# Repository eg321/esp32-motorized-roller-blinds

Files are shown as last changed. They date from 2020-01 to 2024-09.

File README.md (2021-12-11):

*Russian version available [here](README_ru.md)*.

Hi there!

The project is dedictated to control of motorized blinds’ operation and its integration into home automation systems (f.ex. [Home Assistant](https://www.home-assistant.io/) and [OpenHab](https://www.openhab.org/)).

The project developing consists of 2 major areas:

- Software (firmware for boards based at ESP8266 / ESP32 modules)
- Hardware/Mechanical (3d printing models to upgrade your blinds into motorized).

A bit details below...

# ESP8266 / ESP32 firmware
I'm trying to keep compatibility with both platforms.
Main differences between them:
- There is fewer pins available at ESP8266. You can connect 2 steppers to single controller only (using 8 pins).  
- ESP32 can connect up to 4 steppers (or even more?) to single controller (using 16 pins).

If you would to connect 1 or 2 steppers only, use cheaper ESP8266 based controller (like Wemos D1 mini, NodeMCU, etc).

## Features
- Support for cheap 28BYJ-48 steppers (better to use 12 volt versions)
- Control of an unlimited number of steppers (limitation in 4 motors is the default for a more convenient UI). In fact, it's limited by hardware only (by the number of pins).
- Ability to set the rotation speed (12 volt motors can provide a higher speed)
- Ability to set all main settings through  Captive WiFi Portal (steppers used, pins, rotation speed, MQTT settings, etc.)
- Web interface for setting endpoints and controlling blinds (adapted for mobile devices also)
- Possibility of connecting an external mechanical switch (with the ability to stop the curtains in the desired position).
- MQTT support (both for controlling curtains and for setting end positions - can be complete replacement for Web UI)
- Easy integration with popular home automation systems like [Home Assistant](https://www.home-assistant.io/) or [OpenHab](https://www.openhab.org/) (via MQTT)
- Over the air (OTA) updates. No need to disconnect or disassemble the controller to update the firmware. The web interface notifies about the availability of new updates.
- Saving the position of each blind in the ROM (you do not need to re-calibrate or set the position after turning off the power)
- Control of all connected motors in parallel (asynchronous operation with steppers)
- Watchdog (automatic restart of the controller in case of freezing)
- Automatic MQTT re-connection in case of network problems
- Low power consumption when idle (stepper windings are switched-off when idle)
- DHCP over WiFi support

## Web-interface
Control blinds:



Set end-points:



## Captive Portal
You'll be redirected to Captive portal after connecting to "esp-xxxx" WiFi network:



Fill pins for needed Steppers divided by comma and check pins for your mechanical buttons Up/Down (or disable it).

## MQTT
*Just do not setup MQTT details at Captive Portal, if you don't want to use MQTT.*

MQTT details:
- Controller listening for commands at topic `ESP_Blinds/<chip_id>/in` (JSON)
- Controller send updates with state and positions to `ESP_Blinds/<chip_id>/out` (JSON)
- Separate topics for steppers (`/outN`) are disabled for MQTT messaging optimization, but you can enable it if needed for your automation flow.

## HomeAssistant integration
There is MQTT auto-discovery implemented for HomeAssistant with default MQTT prefix (requires HA v2021.11 at least). It assists you to create objects with correct configuration.

In case it does not work for you, you can add blinds manually. See examples below. 


Config example for 2 roller blinds (replace "_chip_Id_" with Chip id of your controller, watch it at registration topic - `/ESP_Blinds/register`):
```yaml
cover:
  - platform: mqtt
    name: "Blind 1"
    device_class: "blind"
    command_topic: "ESP_Blinds/_chip_Id_/in"
    set_position_topic: "ESP_Blinds/_chip_Id_/in"
    set_position_template: '{"num": 1, "action": "auto", "value": {{ 100 - position }} }'
    position_topic: "ESP_Blinds/_chip_Id_/out"
    position_template: '{{ value_json.position1 }}'
    payload_open: '{"num": 1, "action": "auto", "value": 0}'
    payload_close: '{"num": 1, "action": "auto", "value": 100}'
    payload_stop: '{"num": 1, "action": "stop", "value": 0}'
    position_open: 0
    position_closed: 100
    optimistic: false

  - platform: mqtt
    name: "Blind 2"
    device_class: "blind"
    command_topic: "ESP_Blinds/_chip_Id_/in"
    set_position_topic: "ESP_Blinds/_chip_Id_/in"
    set_position_template: '{"num": 2, "action": "auto", "value": {{ 100 - position }} }'
    position_topic: "ESP_Blinds/_chip_Id_/out"
    position_template: '{{ value_json.position2 }}'
    payload_open: '{"num": 2, "action": "auto", "value": 0}'
    payload_close: '{"num": 2, "action": "auto", "value": 100}'
    payload_stop: '{"num": 2, "action": "stop", "value": 0}'
    position_open: 0
    position_closed: 100
    optimistic: false
```
Use same approach for other your blinds.

# Mechanical part
The most popular option uses cheap 28BYJ-48 steppers, but in fact you can use any 4-pin stepper motors (dual winding steppers).
28BYJ-48 is most often used with the ULN2003 driver (better to use 12 volt version, it gives more torque).

I have developed 2 models for converting Leroy Merlin' roller blinds into motorized ones:
1. for the old models. It looks like they are almost not sold anymore.
2. for a new (will publish soon). The fixing holes match the original parts, so the curtains can be easily converted to motorized and vice versa.

3 printing models are available at `3d_parts` directory or at [Thingiverse](https://www.thingiverse.com/thing:4093205/) directly with some instructions.

# Future plans
* Add support for other steppers and drivers (please propose at "issues")
* Add more configuration options at WebUI to allow re-configuration without "wipe settings"
* Prepare universal PCB
* Any ideas? Fill in the Issues.

# Project history
This project appeared as fork of @nidayand [repository](https://github.com/nidayand/motor-on-roller-blind-ws) originally.

Unfortunately, the project supported ESP8266 and 1 stepper only, plus it had not been updated for a long time. I added support for Platformio (for easier development), multiple steppers, and ESP32 later (so more than 2 steppers can be connected to single controller). It was published as v1.4.x.

Soon I wanted a more convenient motor control, a simple controller configuration without firmware re-build, but the original code was of little messy to maintain, although it worked.
As a result, a large refactoring of the firmware took place - new classes and areas of responsibility were allocated.

In fact, it became clear that almost nothing remained of the old project (only the Web UI almost unchanged). This project was detached and now developing on its own tree.

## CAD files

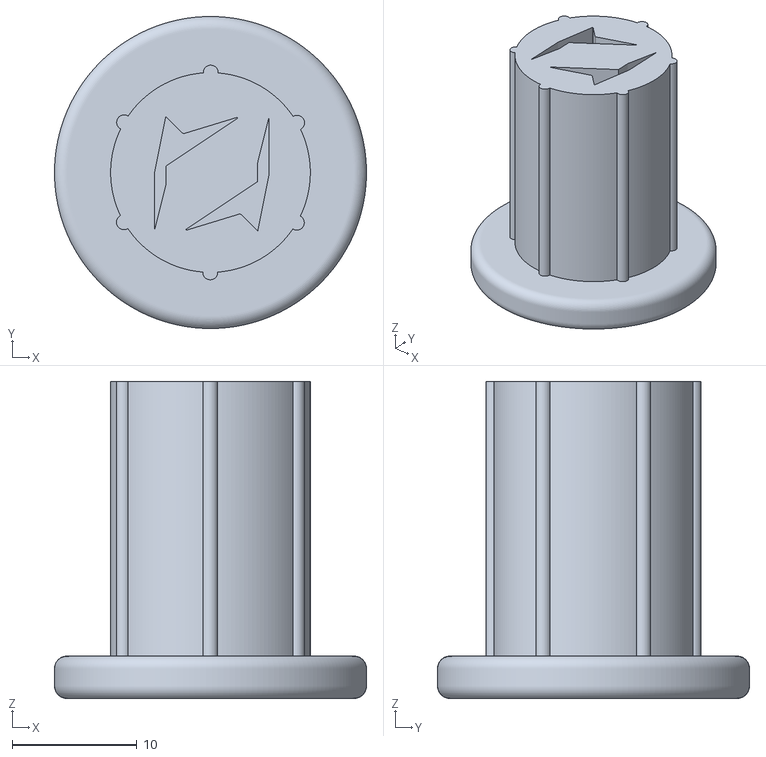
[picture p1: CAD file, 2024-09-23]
3d_parts/Ozon home blind shaft (direct drive).stl
25.0 x 25.0 x 25.4

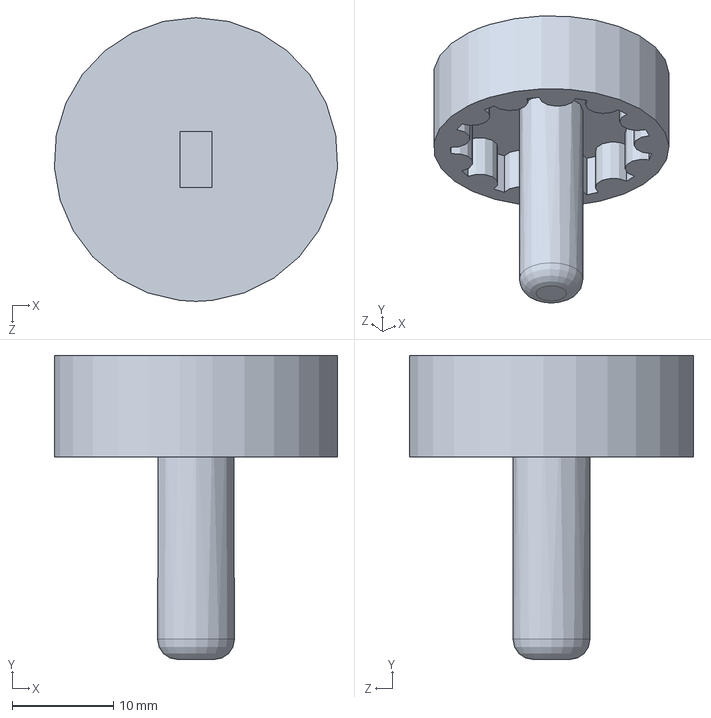
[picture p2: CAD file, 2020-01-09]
3d_parts/Leroy Merlin blind holder (direct drive).SLDPRT
28.0 x 30.0 x 28.0 mm

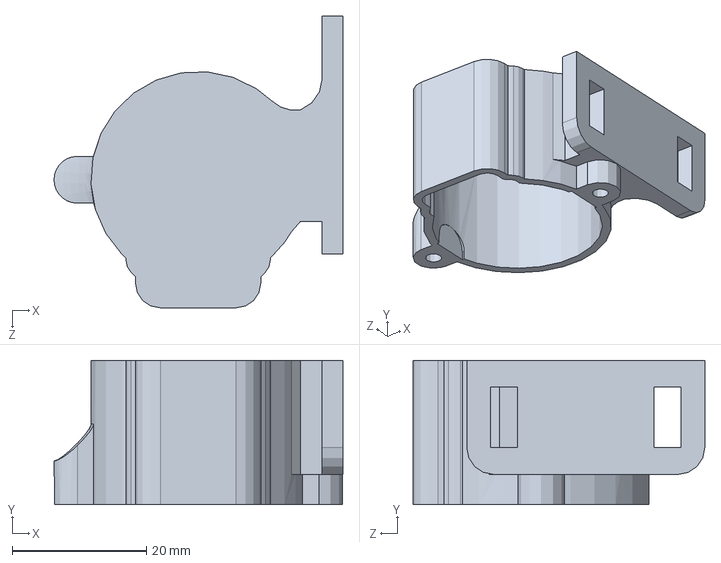
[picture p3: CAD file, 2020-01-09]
3d_parts/Motor holder (direct drive).SLDPRT
43.1 x 21.5 x 43.5 mm

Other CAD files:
3d_parts/Leroy Merlin blind holder (direct drive).STL
3d_parts/Motor holder (direct drive).STL

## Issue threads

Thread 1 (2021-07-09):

static ip and watchdog

iw88881111, 2021-07-09:
Thanks for great project and freeware it :) It's realy working in my SmartHome system (mechanical part another) for three month.
Now, I have 2 suggestions for update (discussed earlier) :
1. Abbility to assign ESP static IP address.
2. Watchdog attached to router/ip address/server etc.

Many thanks
WBR, Igor.

eg321, 2021-08-14:
Hi!

1. Unfortunately "ESP-WiFiSettings" library does not support static IP configuration now. The best option is to request such feature there (highlighting @Juerd). Once they implement it, I'll try to use it here also.
2. There is configured watchdog already. It checks that ESP is working ok and restarting it on any issue. Another part is MQTT - there is automatic reconnection also. One thing that definitely needed to be improved is WiFi connection.
It looks like controller does not reconnect automatically to WiFi. I'll check how we can process this, but as quick workaround I've added possibility to restart board from mechanical switch with 5 clicks. It looks safe, but maybe useful in such situations.
It will be released in v2.0.1.

I'll keep open this issue for now.

iw88881111, 2021-08-22:
Hi!
Maybe set IP/MASK in the main.cpp code?
It's will solved bug :)

eg321, 2021-11-07:
@iw88881111 Igor, I've implemented additional checks for WiFi connectivity. By now it uses such workflow:
1. Once WiFi is disconnected, it waits for 15 min for connection restoration.
2. Once 15 minutes is expired and still no WiFi connection is detected, device is going to restart. Timer is started again for another 15 minutes.

Please note:
1. After restart it can switch to Captive Portal mode, if no WiFi connection still detected. I don't like this, because Captive portal is public and anyone can connect to it during this period, but I cannot find better solution now.
2.  ESP8266 can restore connection immediately without reboot, but ESP32 requires reboot to properly maintain connection (so it always will wait for 15 minutes to expire and try to connect after restart).
3. Device continues handle buttons despite WiFi connection issues (even in Captive portal mode).

I've checked that at my ESP8266 and ESP32 and it works ok for me. You can check these changes at master, if you want.
Later I'll include them into the new release, if no new issues appears.

iw88881111, 2021-11-16:
Hi!
Very well. I wil try new firmware.

eg321, 2022-09-28:
It's not a good practice to make static IP on devices and manage them individually in the network. This should be done at DHCP server side. Almost all routers support this.

I'm closing this issue, because I believe that IP management shouldn't be a part of this device.

Closed 2022-09-28.

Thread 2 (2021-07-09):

turn motor speed (variable)

iw88881111, 2021-07-09:
In testing, when blinds have more length 28byj can not up it.
I change variable "motor speed" to low level (10) and motor worked.
Maybe turn this variable to configuration page.

Thanks.
WBR, Igor.

eg321, 2021-07-11:
Hi,
this implemented in upcoming 2.0 release actually (https://github.com/eg321/esp32-motorized-roller-blinds/commit/51b5972f9db950abd98cf94e50142fe9b9b4165b).
It will allow to change main settings (including motors and pins) at captive portal (yeah, wipe is needed). So, no needs to rebuild your own firmware, because all settings will be stored at FS.
30 RPM by default, but you can decrease it now.
Also, I've added support of 4 motors out of the box.

I'm going to publish it soon, but you already can check it up from master.

Thanks for the issue!

eg321, 2021-08-01:
2.0 is released today: https://github.com/eg321/esp32-motorized-roller-blinds/releases/tag/v2.0

Closing the issue. Feel free to reopen if still actually.

iw88881111, 2021-08-22:
Hi!
1. After uploaded new firmware to ESP32, -  I set stepper speed (RPM) to "10" and blinds really turn slowlk. But after wipe setting from WEB interface it is backing to faster than "10" (I think "30"), even if I set it slowly ("10") in config portal .
Maybe RPM config not saved/loaded correctly?
2. I mean settings for steppers pins in config portal more correctclty named "GPIO NUMBER" not "PIN NUMBER".
3. Not very imporrtant: make RPM setting for each steppers separatly.

Closed 2021-08-01.

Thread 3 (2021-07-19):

General - Installation

phillipmj, 2021-07-19:
Hi,

I'am to this esp8266 programing, I do have a question how to get to compile right, are getting some errors when I open the project in VS. are there a list of dependencies needed to be installed along ?

Best regards
Phillip

eg321, 2021-07-25:
Hi!
All dependencies should be resolved with Platformio (platformio.ini).

Can you provide details for your errors?

Thanks.

phillipmj, 2021-07-26:
Hi,

This are the errors i got

best regadrs
Phillip

I downloaded the file via your "release tap".

Executing task in folder esp32-motorized-roller-blinds-1.4.2: C:\Users\Hiro\.platformio\penv\Scripts\platformio.exe run --target upload <

Processing esp32 (platform: espressif32; board: esp32dev; framework: arduino)
---------------------------------------------------------------------------------------------------------------------------------------------------------------------------------Verbose mode can be enabled via `-v, --verbose` option
CONFIGURATION: https://docs.platformio.org/page/boards/espressif32/esp32dev.html
PLATFORM: Espressif 32 (3.3.0) > Espressif ESP32 Dev Module
HARDWARE: ESP32 240MHz, 320KB RAM, 4MB Flash
DEBUG: Current (esp-prog) External (esp-prog, iot-bus-jtag, jlink, minimodule, olimex-arm-usb-ocd, olimex-arm-usb-ocd-h, olimex-arm-usb-tiny-h, olimex-jtag-tiny, tumpa)
PACKAGES:
 - framework-arduinoespressif32 3.10006.210326 (1.0.6)
 - tool-esptoolpy 1.30100.210531 (3.1.0)
 - tool-mkspiffs 2.230.0 (2.30)
 - tool-openocd-esp32 2.1000.20210401 (10.0)
 - toolchain-xtensa32 2.50200.97 (5.2.0)
LDF: Library Dependency Finder -> http://bit.ly/configure-pio-ldf
LDF Modes: Finder ~ chain, Compatibility ~ soft
Found 31 compatible libraries
Scanning dependencies...
Dependency Graph
|-- <ESP-WiFiSettings> 3.8.0
|   |-- <DNSServer> 1.1.0
|   |   |-- <WiFi> 1.0
|   |-- <SPIFFS> 1.0
|   |   |-- <FS> 1.0
|   |-- <WebServer> 1.0
|   |   |-- <WiFi> 1.0
|   |   |-- <FS> 1.0
|   |-- <WiFi> 1.0
|-- <CheapStepper> 0.2.1
|-- <ArduinoJson> 5.13.4
|-- <FS> 1.0
|-- <SPIFFS> 1.0
|   |-- <FS> 1.0
|-- <DNSServer> 1.1.0
|   |-- <WiFi> 1.0
|-- <WebServer> 1.0
|   |-- <WiFi> 1.0
|   |-- <FS> 1.0
|-- <WiFi> 1.0
|-- <ArduinoOTA> 1.0
|   |-- <Update> 1.0
|   |-- <WiFi> 1.0
|   |-- <ESPmDNS> 1.0
|   |   |-- <WiFi> 1.0
Building in release mode
Compiling .pio\build\esp32\src\NidayandHelper.cpp.o
Compiling .pio\build\esp32\src\main.cpp.o
Generating partitions .pio\build\esp32\partitions.bin
Compiling .pio\build\esp32\lib216\WiFi\ETH.cpp.o
Compiling .pio\build\esp32\lib216\WiFi\WiFi.cpp.o
Compiling .pio\build\esp32\lib216\WiFi\WiFiAP.cpp.o
Compiling .pio\build\esp32\lib216\WiFi\WiFiClient.cpp.o
Compiling .pio\build\esp32\lib216\WiFi\WiFiGeneric.cpp.o
Compiling .pio\build\esp32\lib216\WiFi\WiFiMulti.cpp.o
src\main.cpp:15:30: fatal error: WebSocketsServer.h: No such file or directory

**************************************************************************
* Looking for WebSocketsServer.h dependency? Check our library registry!
*
* CLI  > platformio lib search "header:WebSocketsServer.h"
* Web  > https://platformio.org/lib/search?query=header:WebSocketsServer.h
*
**************************************************************************

compilation terminated.
*** [.pio\build\esp32\src\main.cpp.o] Error 1
In file included from src\NidayandHelper.cpp:2:0:
src\NidayandHelper.h:9:26: fatal error: PubSubClient.h: No such file or directory

**********************************************************************
* Looking for PubSubClient.h dependency? Check our library registry!
*
* CLI  > platformio lib search "header:PubSubClient.h"
* Web  > https://platformio.org/lib/search?query=header:PubSubClient.h
*
**********************************************************************

compilation terminated.
*** [.pio\build\esp32\src\NidayandHelper.cpp.o] Error 1
========================================================================== [FAILED] Took 5.93 seconds ==========================================================================

Environment    Status    Duration
-------------  --------  ------------
esp32          FAILED    00:00:05.927
===================================================================== 1 failed, 0 succeeded in 00:00:05.927 =====================================================================The terminal process "C:\Users\Hiro\.platformio\penv\Scripts\platformio.exe 'run', '--target', 'upload'" terminated with exit code: 1.

Terminal will be reused by tasks, press any key to close it.

eg321, 2021-07-26:
Several dependencies were missed in platformio.ini. It's already fixed in upcoming release 2.0.
You can try it from "master". It's quite stable, but not documented well yet. It includes bunch of fixes and improvements. For example almost all configurations moved to WiFi captive portal (including steppers, pins, speed, etc).

Or you can apply changes from that commit: https://github.com/eg321/esp32-motorized-roller-blinds/commit/f1adf61c16b4bdfcb7aebb582e5a5676e357bd94

eg321, 2021-08-01:
2.0 is released today: https://github.com/eg321/esp32-motorized-roller-blinds/releases/tag/v2.0

Closing the issue. Feel free to reopen if still actually.

Closed 2021-08-01.

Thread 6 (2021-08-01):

v2 boot loop

nikkisstuff, 2021-08-01:
Ive built and flashed v2 esp8266 version but it is stuck in a boot loop. This is the output from the esp exception decoder

Exception 28: LoadProhibited: A load referenced a page mapped with an attribute that does not permit loads
PC: 0x40220284
EXCVADDR: 0x0003aaaa

Decoding stack results

eg321, 2021-08-02:
Hi!
Have you erased it before flashing? Most probably old config conflicts with new codebase.

I have one esp8266 working fine with v2.

nikkisstuff, 2021-08-02:
I have erased the board and i still have the same problem. I then tried am 2nd board and its just the same. This is the output from the build.
> Executing task: C:\Users\nikki\.platformio\penv\Scripts\platformio.exe run --environment esp12e <

Processing esp12e (platform: espressif8266; board: nodemcuv2; framework: arduino)
------------------------------------------------------------------------------------------------------------------------------------------------------------------Verbose mode can be enabled via `-v, --verbose` option
CONFIGURATION: https://docs.platformio.org/page/boards/espressif8266/nodemcuv2.html
PLATFORM: Espressif 8266 (3.1.0) > NodeMCU 1.0 (ESP-12E Module)
HARDWARE: ESP8266 80MHz, 80KB RAM, 4MB Flash
PACKAGES:
 - framework-arduinoespressif8266 3.30001.210627 (3.0.1)
 - tool-esptool 1.413.0 (4.13)
 - tool-esptoolpy 1.30000.201119 (3.0.0)
 - toolchain-xtensa 2.100300.210717 (10.3.0)
LDF: Library Dependency Finder -> http://bit.ly/configure-pio-ldf
LDF Modes: Finder ~ chain, Compatibility ~ soft
Found 41 compatible libraries
Scanning dependencies...
Dependency Graph
|-- <ESP-WiFiSettings> 3.8.0
|   |-- <DNSServer> 1.1.1
|   |   |-- <ESP8266WiFi> 1.0
|   |-- <ESP8266WebServer> 1.0
|   |   |-- <ESP8266WiFi> 1.0
|   |-- <ESP8266WiFi> 1.0
|   |-- <LittleFS> 0.1.0
|-- <CheapStepper> 0.2.1
|-- <ArduinoJson> 5.13.4
|-- <Button2> 1.6.2
|-- <WebSockets> 2.3.6
|   |-- <ESP8266WiFi> 1.0
|   |-- <Ethernet> 2.0.0
|   |   |-- <SPI> 1.0
|   |-- <SPI> 1.0
|   |-- <Hash> 1.0
|   |-- <ESP8266WebServer> 1.0
|   |   |-- <ESP8266WiFi> 1.0
|-- <PubSubClient> 2.8.0
|-- <ESP8266WebServer> 1.0
|   |-- <ESP8266WiFi> 1.0
|-- <LittleFS> 0.1.0
|-- <DNSServer> 1.1.1
|   |-- <ESP8266WiFi> 1.0
|-- <ESP8266WiFi> 1.0
|-- <ArduinoOTA> 1.0
|   |-- <ESP8266WiFi> 1.0
|   |-- <ESP8266mDNS> 1.2
|   |   |-- <ESP8266WiFi> 1.0
Building in release mode
Compiling .pio\build\esp12e\src\Helpers\ButtonsHelper.cpp.o
Compiling .pio\build\esp12e\src\Helpers\ConfigHelper.cpp.o
Compiling .pio\build\esp12e\src\Helpers\MqttHelper.cpp.o
Compiling .pio\build\esp12e\src\Helpers\StepperHelper.cpp.o
Compiling .pio\build\esp12e\src\main.cpp.o
Generating LD script .pio\build\esp12e\ld\local.eagle.app.v6.common.ld
Compiling .pio\build\esp12e\libbdf\ESP8266WiFi\BearSSLHelpers.cpp.o
Compiling .pio\build\esp12e\libbdf\ESP8266WiFi\CertStoreBearSSL.cpp.o
Compiling .pio\build\esp12e\libbdf\ESP8266WiFi\ESP8266WiFi.cpp.o
src\main.cpp: In function 'void webSocketEvent(uint8_t, WStype_t, uint8_t*, size_t)':
src\main.cpp:213:12: warning: enumeration value 'WStype_ERROR' not handled in switch [-Wswitch]
  213 |     switch (type) {
      |            ^
src\main.cpp:213:12: warning: enumeration value 'WStype_BIN' not handled in switch [-Wswitch]
src\main.cpp:213:12: warning: enumeration value 'WStype_FRAGMENT_TEXT_START' not handled in switch [-Wswitch]
src\main.cpp:213:12: warning: enumeration value 'WStype_FRAGMENT_BIN_START' not handled in switch [-Wswitch]
src\main.cpp:213:12: warning: enumeration value 'WStype_FRAGMENT' not handled in switch [-Wswitch]
src\main.cpp:213:12: warning: enumeration value 'WStype_FRAGMENT_FIN' not handled in switch [-Wswitch]
src\main.cpp:213:12: warning: enumeration value 'WStype_PING' not handled in switch [-Wswitch]
src\main.cpp:213:12: warning: enumeration value 'WStype_PONG' not handled in switch [-Wswitch]
src\main.cpp: In function 'void mqttCallback(char*, byte*, unsigned int)':
src\main.cpp:233:24: warning: comparison of integer expressions of different signedness: 'int' and 'unsigned int' [-Wsign-compare]
Compiling .pio\build\esp12e\libbdf\ESP8266WiFi\ESP8266WiFiAP.cpp.o
  233 |     for (auto i = 0; i < length; i++) {
      |                      ~~^~~~~~~~
Compiling .pio\build\esp12e\libbdf\ESP8266WiFi\ESP8266WiFiGeneric.cpp.o
Compiling .pio\build\esp12e\libbdf\ESP8266WiFi\ESP8266WiFiGratuitous.cpp.o
Compiling .pio\build\esp12e\libbdf\ESP8266WiFi\ESP8266WiFiMulti.cpp.o
Compiling .pio\build\esp12e\libbdf\ESP8266WiFi\ESP8266WiFiSTA-WPS.cpp.o
Compiling .pio\build\esp12e\libbdf\ESP8266WiFi\ESP8266WiFiSTA.cpp.o
Compiling .pio\build\esp12e\libbdf\ESP8266WiFi\ESP8266WiFiScan.cpp.o
Compiling .pio\build\esp12e\libbdf\ESP8266WiFi\WiFiClient.cpp.o
Compiling .pio\build\esp12e\libbdf\ESP8266WiFi\WiFiClientSecureBearSSL.cpp.o
Compiling .pio\build\esp12e\libbdf\ESP8266WiFi\WiFiServer.cpp.o
Compiling .pio\build\esp12e\libbdf\ESP8266WiFi\WiFiServerSecureBearSSL.cpp.o
Compiling .pio\build\esp12e\libbdf\ESP8266WiFi\WiFiUdp.cpp.o
Compiling .pio\build\esp12e\libbdf\ESP8266WiFi\enable_wifi_at_boot_time.cpp.o
Compiling .pio\build\esp12e\lib5ef\DNSServer\DNSServer.cpp.o
Compiling .pio\build\esp12e\lib1d3\ESP8266WebServer\detail\mimetable.cpp.o
Archiving .pio\build\esp12e\lib1d3\libESP8266WebServer.a
Compiling .pio\build\esp12e\libbbf\LittleFS\LittleFS.cpp.o
Compiling .pio\build\esp12e\libbbf\LittleFS\lfs.c.o
Archiving .pio\build\esp12e\libbdf\libESP8266WiFi.a
Compiling .pio\build\esp12e\libbbf\LittleFS\lfs_util.c.o
Archiving .pio\build\esp12e\lib5ef\libDNSServer.a
Compiling .pio\build\esp12e\libe9b\ESP-WiFiSettings\WiFiSettings.cpp.o
Compiling .pio\build\esp12e\lib9b0\CheapStepper\CheapStepper.cpp.o
.pio\libdeps\esp12e\CheapStepper\CheapStepper.cpp: In constructor 'CheapStepper::CheapStepper()':
.pio\libdeps\esp12e\CheapStepper\CheapStepper.cpp:29:49: warning: list-initializer for non-class type must not be parenthesized
   29 | CheapStepper::CheapStepper () : pins({8,9,10,11}) {
      |                                                 ^
.pio\libdeps\esp12e\CheapStepper\CheapStepper.cpp: In constructor 'CheapStepper::CheapStepper(int, int, int, int)':
.pio\libdeps\esp12e\CheapStepper\CheapStepper.cpp:35:89: warning: list-initializer for non-class type must not be parenthesized
   35 | CheapStepper::CheapStepper (int in1, int in2, int in3, int in4) : pins({in1,in2,in3,in4}) {
      |                                                                                         ^
.pio\libdeps\esp12e\CheapStepper\CheapStepper.cpp: In member function 'void CheapStepper::run()':
.pio\libdeps\esp12e\CheapStepper\CheapStepper.cpp:137:30: warning: comparison of integer expressions of different signedness: 'long unsigned int' and 'int' [-Wsign-compare]
  137 |  if (micros() - lastStepTime >= delay) { // if time for step
      |      ~~~~~~~~~~~~~~~~~~~~~~~~^~~~~~~~
Archiving .pio\build\esp12e\libfa5\libArduinoJson.a
Archiving .pio\build\esp12e\libbbf\libLittleFS.a
Compiling .pio\build\esp12e\lib1bd\Button2\Button2.cpp.o
Compiling .pio\build\esp12e\libd93\SPI\SPI.cpp.o
Archiving .pio\build\esp12e\lib9b0\libCheapStepper.a
Compiling .pio\build\esp12e\libf4d\Ethernet\Dhcp.cpp.o
Archiving .pio\build\esp12e\lib1bd\libButton2.a
Compiling .pio\build\esp12e\libf4d\Ethernet\Dns.cpp.o
Archiving .pio\build\esp12e\libd93\libSPI.a
Compiling .pio\build\esp12e\libf4d\Ethernet\Ethernet.cpp.o
Compiling .pio\build\esp12e\libf4d\Ethernet\EthernetClient.cpp.o
Compiling .pio\build\esp12e\libf4d\Ethernet\EthernetServer.cpp.o
Archiving .pio\build\esp12e\libe9b\libESP-WiFiSettings.a
Compiling .pio\build\esp12e\libf4d\Ethernet\EthernetUdp.cpp.o
Compiling .pio\build\esp12e\libf4d\Ethernet\socket.cpp.o
Compiling .pio\build\esp12e\libf4d\Ethernet\utility\w5100.cpp.o
Compiling .pio\build\esp12e\lib2fb\Hash\Hash.cpp.o
Compiling .pio\build\esp12e\libe65\WebSockets\SocketIOclient.cpp.o
Compiling .pio\build\esp12e\libe65\WebSockets\WebSockets.cpp.o
Archiving .pio\build\esp12e\libf4d\libEthernet.a
Compiling .pio\build\esp12e\libe65\WebSockets\WebSocketsClient.cpp.o
Archiving .pio\build\esp12e\lib2fb\libHash.a
Compiling .pio\build\esp12e\libe65\WebSockets\WebSocketsServer.cpp.o
Compiling .pio\build\esp12e\libe65\WebSockets\libb64\cdecode.c.o
Compiling .pio\build\esp12e\libe65\WebSockets\libb64\cencode.c.o
Compiling .pio\build\esp12e\libe65\WebSockets\libsha1\libsha1.c.o
Compiling .pio\build\esp12e\lib9b0\PubSubClient\PubSubClient.cpp.o
Compiling .pio\build\esp12e\lib4db\ESP8266mDNS\ESP8266mDNS.cpp.o
Compiling .pio\build\esp12e\lib4db\ESP8266mDNS\LEAmDNS.cpp.o
Archiving .pio\build\esp12e\libe65\libWebSockets.a
.pio\libdeps\esp12e\PubSubClient\src\PubSubClient.cpp: In member function 'boolean PubSubClient::publish_P(const char*, const uint8_t*, unsigned int, boolean)':
.pio\libdeps\esp12e\PubSubClient\src\PubSubClient.cpp:523:16: warning: comparison of integer expressions of different signedness: 'unsigned int' and 'int' [-Wsign-compare]
  523 |     return (rc == expectedLength);
      |             ~~~^~~~~~~~~~~~~~~~~
Compiling .pio\build\esp12e\lib4db\ESP8266mDNS\LEAmDNS_Control.cpp.o
Archiving .pio\build\esp12e\lib9b0\libPubSubClient.a
Compiling .pio\build\esp12e\lib4db\ESP8266mDNS\LEAmDNS_Helpers.cpp.o
Compiling .pio\build\esp12e\lib4db\ESP8266mDNS\LEAmDNS_Structs.cpp.o
Compiling .pio\build\esp12e\lib4db\ESP8266mDNS\LEAmDNS_Transfer.cpp.o
Compiling .pio\build\esp12e\lib354\ArduinoOTA\ArduinoOTA.cpp.o
Archiving .pio\build\esp12e\libFrameworkArduinoVariant.a
Compiling .pio\build\esp12e\FrameworkArduino\Crypto.cpp.o
Compiling .pio\build\esp12e\FrameworkArduino\Esp-frag.cpp.o
Archiving .pio\build\esp12e\lib4db\libESP8266mDNS.a
Compiling .pio\build\esp12e\FrameworkArduino\Esp-version.cpp.o
Compiling .pio\build\esp12e\FrameworkArduino\Esp.cpp.o
Compiling .pio\build\esp12e\FrameworkArduino\FS.cpp.o
Archiving .pio\build\esp12e\lib354\libArduinoOTA.a
Compiling .pio\build\esp12e\FrameworkArduino\FSnoop.cpp.o
Compiling .pio\build\esp12e\FrameworkArduino\FunctionalInterrupt.cpp.o
Compiling .pio\build\esp12e\FrameworkArduino\HardwareSerial.cpp.o
Compiling .pio\build\esp12e\FrameworkArduino\IPAddress.cpp.o
Compiling .pio\build\esp12e\FrameworkArduino\LwipDhcpServer-NonOS.cpp.o
Compiling .pio\build\esp12e\FrameworkArduino\LwipDhcpServer.cpp.o
Compiling .pio\build\esp12e\FrameworkArduino\LwipIntf.cpp.o
Compiling .pio\build\esp12e\FrameworkArduino\LwipIntfCB.cpp.o
Compiling .pio\build\esp12e\FrameworkArduino\MD5Builder.cpp.o
Compiling .pio\build\esp12e\FrameworkArduino\Print.cpp.o
Compiling .pio\build\esp12e\FrameworkArduino\Schedule.cpp.o
Compiling .pio\build\esp12e\FrameworkArduino\StackThunk.cpp.o
Compiling .pio\build\esp12e\FrameworkArduino\Stream.cpp.o
Compiling .pio\build\esp12e\FrameworkArduino\StreamSend.cpp.o
Compiling .pio\build\esp12e\FrameworkArduino\Tone.cpp.o
Compiling .pio\build\esp12e\FrameworkArduino\TypeConversion.cpp.o
Compiling .pio\build\esp12e\FrameworkArduino\Updater.cpp.o
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
eg321, 2021-08-02:
Can you enable esp8266_exception_decoder and provide stacktrace here please? It can help to find rootcause.

https://docs.platformio.org/en/latest//core/userguide/device/cmd_monitor.html#cmd-device-monitor-filters

it can be enabled at "monitor_filters" in platformio.ini.

Also, what board do you use? As I can see: `HARDWARE: ESP8266 80MHz, 80KB RAM, 4MB Flash`
But uploader shows "1044464 bytes" at your flash. It looks strange.

nikkisstuff, 2021-08-02:
Yes I am using "HARDWARE: ESP8266 80MHz, 80KB RAM, 4MB Flash" am using this to get the output. I have done a fresh flash of v1.4.2 and it is working perfectly

[env:log_output_to_file]
platform = espressif8266
board = nodemcuv2
monitor_filters = esp8266_exception_decoder

here is the log output
https://drive.google.com/drive/folders/1ejygLXW3mg4O0sA7DSVw5WjxLC8ueBJE?usp=sharing

nikkisstuff, 2021-08-03:
I've just tried on a 3rd board new out of the packet and i get the same error

nikkisstuff, 2021-08-05:
I have rolled back to V1.4.2. and everything is working fine again

Closed 2021-08-05.

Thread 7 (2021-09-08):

Add ADC reading to MQTT

burjakremen, 2021-09-08:
Thanks to the author for a wonderful project !!!
Is it possible to implement ADC reading and output the result in MQTT into the project (ESP8266 pin A0)?

eg321, 2021-09-08:
glad to hear that it useful for you!

Can you describe your scenario please? Why do you need some ADC readings on MQTT?

burjakremen, 2021-09-08:
I am planning to make a stand-alone system powered by a battery that will be charged by a solar panel. Using the ADC, need to get the level of the current battery charge.

eg321, 2021-09-11:
It don't looks as popular scenario, but I'll think what we can do here. Thanks for your idea!

burjakremen, 2021-09-13:
You can consider many scenarios in which an ADC is used, as an example - connecting a light sensor

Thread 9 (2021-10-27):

Looped reboots at Wemos D1 mini

eg321, 2021-10-27:
Hey thanks for the answer. I tried it on platformio and i works fine. but i have a new issue that i cant solve. if is set the wifi settings in ap and restart and watch monitoring, the wemos locks like they dont connect or just reboots every time. So there is my wifi ssid then try to connect and then repeat with exception error 28, do i must need mqtt? i think no, so i dont know why it dont work. I reset the setting many times and be sure all values are correct but no success.

_Originally posted by @develarts in https://github.com/eg321/esp32-motorized-roller-blinds/issues/8#issuecomment-953169740_

eg321, 2021-11-08:
Closing as fixed. Let me know, if I'm wrong.

Closed 2021-11-08.

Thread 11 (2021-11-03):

Slow RPM when using 3 Motors

Caliban2017, 2021-11-03:
Hello,

first of all respect for this nice Code. I use it on 7 of my Windows now and it works very well so far, with one exception.

I have two double Windows, where i can use a Wemos D1 Mini to run two 28RYJ Motors. It work very well so far on the Wemos, i only use the 5V Version but when i set the RPM to max 20, it can lower and raise the blinds without Problems. The Speed is acceptable. But i have a bigger Window mit 3 Blinds on it, so i needed to use a ESP32Dev1 to use more than two Motors. When i control one Motor, it lower and raises a little bit slower then the Wemos D1. But the main Problem is, when i use all three Motors at the same time, the RPM is reduced to maybe 8-10-ish?! It goes very slow up and down. I tried to change the RPM and wiped the Settings and raised it to 40 RPM, but it does not help. The Motors always driving at the same Speed. Maybe the RPM is ignored in the Config?! But i think it has something to do with driving all three Motors at the same time. Maybe the ESP32 is to slow for that? Do you know any Solution for it or what i can try to fix it? I can accept the slow speed for the Moment, but when there is a fix to open and close them a little bit faster, i would very appreciate it.

And i have a suggestion for upcoming Version - maybe it is possible to use different RPM Speeds for Up and Down Movements? Because i recognized, the Down RPM can be much higher than the Up-Movement of the 28RYJ, especially on the 5V Version of the Motor. Because there is Tourqe on the Motor, when the blinds are lowering.

Would really love to see new Versions here, because its a nice Program, it works very nice but the configuration is a problen to wipe the complete Settings all the time.

Thank you very much and greetings from Germany,
Caliban

eg321, 2021-11-04:
Hello, Caliban.
Thank you for your feedback! Glad to know that it's useful for someone else.

**Regarding speed:**
ULN2003 is actually an array of gates. It's not a real driver to work with steppers where we can define direction and command "do a step". This means that ESP should process by self each microstep for each motor.
It's a problem when we want to handle several steppers in parallel.
I've switched to the new async handling of steppers at v1.4.0 to minimize this issue. By now second, third stepper affects performance, but not in 2x or 3x slower as it was before (moreover not in 8-10x slower). Maybe there some space for optimization, but I don't think that it will work much better at that hardware.

I think there is one option to move forward: use real drivers like a4988 and maybe another steppers, but it will not so cheap as ULN2003  + 28byj-48.
I don't have a time to implement support of such drivers now, but can assist you, if you have skills.

I'm using 12v version of 28byj-48, and it works quite good (3 steppers per single esp32 board). I really recommend to switch to 12v stepper. Maybe it's most simple and cheap solution to improve situation with speed now.

**Regarding reconfiguration issue:**
Yes, it's on my TODO list. Unfortunately library that I use for settings does not allow to reconfigure settings without wipe. And it looks as not maintained anymore. Most probably I'll switch soon to another library without such issues.
During this switch I'm going to add more settings (including separate up/down speeds).

What version do you use? I hope it's a v2.0.

Once again, I don't have much time for this project now, but I can apply proposed changes as "Pull requests". Feel free to contribute.

Thanks for feedback!

Caliban2017, 2021-11-04:
Hi eg321,

thank you for your Anwser and your Explanation how the ULN2003 Driver works. I already throught that, the ESP seems to be to slow to drive all three Motors at the same time. Of course there would be the possibility to use two Wemos D1 instead of one ESP32. But i wanted to keep the Energy Consumption of that project as low as possible. I can accept that speed, of course it would be nice to get them faster but i don't want to spend more Money into that Project. It was more a Just-For-Fun Thing to try that and it works very well in combination with Home Assistant.

i already saw that alternative way to modify the Steppermotor from Unipolar to Bipolar and use a H-Bridge Driver. But yes, it would be not as cheap as the ULN2003 + 28BYJ.

I tried to avoid the 12V version too, because i wanted to power the ESP and the Steppers from the same Power Source (keep the Energy Consumption low). So 5v was the better Solution for me, because i can simply use a USB Power-Plug (5V, 2A) to power both the Wemos/ESP32 and the Motors at the same time. For a 12V Source i would need to step down the 12V to 5V for the Wemos/ESP32.

But maybe i will try to switch to two Wemos instead of one ESP32, because i want try to connect a fourth Motor for my Blinds they are in front of my Window. I don't know the right Translation for it, Google says "Lamellar curtain" or "vertical Blinds". You can open them by a Ball-Chain and my Idea was to use your Script and the fourth Motor to drive that Chain to open and close that Blind too. But i think when 3 Motors are already to much, i should switch to the two Wemos D1.

I hope still to see some more work from you, that script is really nice and meets all my needs to integrate them perfectly in Home Assistant and Google Assistant.

Oh and one more Tip for the integration in Home Assistant: you should change optimistic: false to true, because with False Google Assistant always gives an Error Message opening and closing the Blind. After my research for that Problem, it has to do with a stateless Blind and how Google handle them. The command will work, it will raise and lower the Blind but it will give a Error Respond. But with changing that to true, all works without Errors.

Greetings

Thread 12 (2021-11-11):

Different RPM Speed in Home and Settings-Screen

Caliban2017, 2021-11-11:
Hello again,

i noticed another strange behaviour in this Script. The RPM Speed is a different in the Settings Screen, where i can set the Min and Max Position for the Blind then in the Home-Screen, where i actually control the Blinds. It is in the Settings always faster then in the Home Screen, it may cause the Problem the Motor will skip steps or have not enough Torgue to lift the Blind, when not running on 12v. For example i set the RPM to 30 in the Setup Routine, it can raise and lower the Blind in the Homescreen but when i try to lower the Blind in the Settingsscreen to set max Positions, the Motor has another higher pitched Sound and it runs faster but sometimes it stops for a Second and then it moves again. This is causing the Problem the min and max Position is not correct at the End. Its just running to fast. But it seems to depent on the set RPM in the Setup. Maybe there is a Value added to the RPM Value for the Setup-Screen? It feels always like i set 30 RPM and it moves like 30+20 RPM in the Settings Screen. Or maybe 30*2.

I tried to find something in the Code that is causing that, but my knowlegde seems to be on the limit, so i don't find it.

Maybe you can give some sort of Info how to fix it or fix it in your Code? It would be much easier to setup the Blinds at higher RPM without loosing Steps.

Greetings,
Caliban

eg321, 2021-11-17:
Hi,

Usual operations and settings screen uses the same Stepper object with same RPM settings.
One difference only: "Settings" screen uses synchronous control of stepper, because no needs to process other steppers during this period. So, it's like exclusive access to controller.

I've checked at my installation (ESP32 + 12v Steppers) and do not see any difference in speed (Home / Settings screen).
As I remember, you're using ESP8266. Can you try your steppers with ESP32?

Frank1604, 2021-11-18:
I have exact the same issue here with an ESP8266. In the settings screen, the motor (12V, ULN2003) ist stuttering and sounds weird.
I tried with an ESP32 and this works fine.

Caliban2017, 2021-11-19:
Hello,

Yes, i use the ESP8266 and the 5V Stepper with ULN2003. The ESP32 works finde in this case. But i swapped out the ESP32 to two Wemos D1, because it is much faster with the 5V Motors. The ESP32 is just to slow to control more than two Motors. When all is set up correct, the Script is working so nice, it is already Part of my daily Smart Home use and always works like a charm. But the Setup is really annoying because of the Wipe Settings Thing and this Problem with the different RPM which causes the Stepper to slip/lose Steps.

eg321, 2021-11-29:
Guys, regarding initial issue - different speed (and sound) at "home" and "settings" screens are ok, because they uses different methods as I mentioned above.
Codebase for ESP32 and ESP8266 almost the same. Sorry, I don't have ideas and time to look deeper now. Maybe it's some issue at used library... maybe not.

@Caliban2017 Anyway, "ESP32 is just to slow to control more than two Motors" looks strange for me. I'm using ESP32 with 3 motors connected everyday (12v). There is not many difference in speed between 1-2-3 motors in parallel. Can you check your installation with timer to be absolutely objective (1-2-3 steppers in parallel)? What mechanic are you using?

Antikillerbm, 2022-10-29:
It's because in setup mode motor running with blocking sketch, intill the interrupt
In auto mode motor do the step, then do the sketch, then do another step. Probably esp32 working a bit faster.

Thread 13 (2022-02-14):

Moving from my old nidayand fork

Antikillerbm, 2022-02-14:
Ive done another fork from nidayand original project and still use it about 3 years.
Now I want to change my 3pcs 8266 to one ESP32. The problem is I use 3 separate buttons for 3 blinds, long press - up, short - down for each
I want to update everything but leave 3 separate buttons on my fancy touch panel))
Your code seems complicated, may be u can provide some help or advices, how to add extra bottons and change yhe functionality.
Thanks.

eg321, 2022-02-14:
Hi,

Do you often use separate buttons to control separate blinds?
I've checked different configurations and it looks like in most scenarios I do not want to control each blind separately. I'm quite rarely use buttons at all.
At most cases my automation does all work (open at morning and close at evening). At other cases I'm using voice assistant to control blinds (or from mobile / PC). And here I'm control all blinds as single entity again (but can control specific blinds).

So, I suppose buttons just as backup option to control blinds when there is some issue with home automation (buttons will work even without wi-fi connection). I'm using simple 2-buttons switch with arrows: up and down.
However I've implemented some additional logic to these 2 buttons:
1. Short press - move up/down to the limit. Another short click will stop movement.
2. Long press - move up/down until button pressed.
3. 5 quick clicks to reboot device.

You can find this code here: https://github.com/eg321/esp32-motorized-roller-blinds/blob/master/src/main.cpp#L302

Antikillerbm, 2022-02-14:
Actualy u right, is not often at all. Why I made 3 buttons, because after automations done with blinds, every peice can stay in different position. Logicaly is not right, you push the button and all curtains start moving in the same direction, regardless of the difference in their positions. Better if they align position firs then move together.

eg321, 2022-02-14:
>  Logicaly is not right, you push the button and all curtains start moving in the same direction, regardless of the difference in their positions.
Sorry, can't agree with you here. Short click at my FW means "full open/close" command. So, all blinds are trying to get their final state asap. Not sure if I want to wait while single blind is going to position of another 2 blinds, before they all will going down.
But visually it will better, I think.

Probably such movement strategy can be realized as option:
1. Move all blinds ASAP.
2. Align blinds and then move them only.

Someone will prefer first option, and someone second one.
I can't promise you to implement that feature, but I'm always open for Pull request. You're welcome to prepare such changes in your fork and propose them as Pull request.

Just as workaround for current movement strategy:  you can up all blinds and then move it down together.

Antikillerbm, 2022-02-15:
Yeah, technically u get more light in less time, but total openning time will be equal.
First i will update software without any changes in hardware (so i need to leave only one button for one device) because with my current firmware, access getting lost until reboot, after wifi down for a while.
Btw does your OTA compatible with nidayand original OTA? Or i need wire it up for flashing?

eg321, 2022-02-15:
It's the same Arduino OTA protocol. So, most probably, yes, it should be compatible, but I've not checked such upgrades.

Antikillerbm, 2022-02-15:
Ok, Thank you for quick replies, I will work on soon, let's see how it goes

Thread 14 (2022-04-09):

Stepper Motor stuck.

Electr1fying, 2022-04-09:
Hi eg321!

I just installed your 2.0.1 Binary on a Wemos D1 Mini, but there is something wrong with the pin layout or something. IN3 and IN4 are permanently lit.

Can you perhaps provide some guidance on the pin layout in your software? I get the feeling 1 isn't 1 but perhaps meant as (e.g) GPIO5?

Thanks in advance!

Electr1fying, 2022-04-10:
So i managed to find out that the pins you need to fill in into the configuration are the GPIO pins, so in case of the Wemos D1 Mini, it is 5,4,0,2 for one Stepper motor.

Closing this issue. Thanks!

Closed 2022-04-10.

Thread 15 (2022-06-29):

Control with one button

Antikillerbm, 2022-06-29:
Add this option to the main project if you want
https://github.com/Antikillerbm/esp32-motorized-roller-blinds

eg321, 2022-06-29:
Hi,
Your changes currently remove possibility to control blinds with up/down switch.
I'll gladly accept your changes once you'll implement them as separate option, not removing current options.

Thanks.

Antikillerbm, 2022-06-29:
Now you can select by defining the parameter

eg321, 2022-06-29:
Can you create pull request from your fork please?
It's better to discuss changes there.

Closed 2022-10-03.

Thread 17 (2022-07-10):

Different Stepper Motor

KaeShoru, 2022-07-10:
Hello. I tried to make a curtain with the motor that is written in the article, but it turned out to be too weak for my curtain. I have tried both 5 volt and 12 volt versions. I also changed power supplies, however The roller blind only went down but didn't go up. Hence the question: is it possible to connect a nema17 instead of28BYJ-48. And how to do it?

eg321, 2022-07-14:
Hi!
Are you sure that wirings is correct? If you switch one of phase line on motor, torque will decrease drastically.
Also, check your ULN2003 driver. All 4 leds should blink on the move during correct work.

I'm using several blinds with 28BYJ-48 12v each day for couple years. They are not fast, but always open\close my blinds correctly without any issues.

About nema12 - yes, most probably it can be integrated without huge issues. Main issue: "CheapStepper" library (that used currently) does not support nema17 motors and drivers. It should be switched to some another library.

If you'll adapt codebase for Nema17, please tell me. I'll try to assist you to easily integrate your changes into upstream branch.

KaeShoru, 2022-07-15:
Yes, I connected everything correctly, as far as I can tell. I also registered connections as "5,4,0,2" as written earlier. The motor rotates in both directions, but it seems to lack torque. Perhaps I need to remove the jumper on the power circuit 5v on ULN2003? To be honest, I have never done anything like this before, so I may not understand something.

RobertRupa, 2022-08-07:
Check connections between stepper motor and ULN2003. Connecting nema motors should b no problem if max rating of driver and power supply are not exceed.

KaeShoru, 2022-08-13:
The connection between the motor and the controller is implemented through connectors, there is nothing to confuse here. During this time, I tried motors from different places and different power supplies, but the torque is still not enough.The motor just broke after several attempts to raise the shade. As I understand it, it is simply too heavy for this motor (1,4 length and blackout material).

eg321, 2022-09-28:
It looks as some HW issue for me. Closing this issue. Please create another one, if you think I'm wrong.

Closed 2022-09-28.

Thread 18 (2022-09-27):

28BYJ-48 12v motor - how long blackout blinds it can handle?

roulendz, 2022-09-27:
For what blind lengths other people use 28BYJ-48 12v?

Because I have 2.4m long blackout blinds, and wondering if it will work. 🤔

Thank you.

eg321, 2022-09-28:
Hi,

I'm using 28BYJ-48 12v  for ~1.5m blackout blinds more than 2 years. It's ok for this size. If torque will be not enough, you can configure speed (smaller speed - more torque) - firmware allows that. It's not a big difference to open blind in 1 minute or 2 minutes for me, because I'm opening it automatically by HA each morning.

It will be great, if someone else share their experience.

Closed 2024-11-15.

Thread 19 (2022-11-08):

question about more than 4 stepper

eduesp32, 2022-11-08:
Hi Egor. Thank you for the work done. If it doesn't bother you, help me with advice on how to expand this firmware to work with a little more motors. everything works great with 4 stepper motors. I haven't figured out the home assistant yet, but I hope I'll set it up somehow. Is it possible to make a connection via a pcf8574 type expander over the i2c bus, I just need a slightly larger number of steppers. How can I increase the number of motors in the interface? To be honest, I want to connect 16 steppers, and I don't want to occupy 4 esp 32 with them. But there is a necessary number of expanders. There are examples of connecting stepper motors via i2c on the network, but only for arduino, and unfortunately I didn't find anything with the esp. Thank you in advance for the answer.

eg321, 2022-11-08:
Hi!
Glad to see it's useful for you. Feel free to give a star to this repo ;)

I've not tried this, but it looks possible with some changes.

1. From interface side you should change that line at `main.cpp`:
https://github.com/eg321/esp32-motorized-roller-blinds/blob/c73b0099cf9474bf3646499c489f52eed5b7ea85/src/main.cpp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

It will be enough to update web interface with needed bars and configurations for each stepper. MQTT part also will be updated automatically.

2. Main issue will be adapting `CheapStepper` library to work with i2c expander. It doesn't know about expanders and does not know how to work with them. As quick dirty hack, you can replace `pinMode` with `pcf8574.pinMode` (or what library you'll use) and `digitalWrite` with `PCF8574.digitalWrite` and so on.

3. Also do not forget to update this function:
https://github.com/eg321/esp32-motorized-roller-blinds/blob/c73b0099cf9474bf3646499c489f52eed5b7ea85/src/Helpers/StepperHelper.cpp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

And that's it.

If you'll find better way, please tell me. I'll try to support that. This definitely can be useful.

Please keep us updated about results. It's quite interesting experiment.

eduesp32, 2022-11-09:
Hi. Thank you for your prompt reply. I will try your advice. I'm just  starting to learn esp 32.  I have never done coding at all, I will study it slowly. Most of the connected sensors and modules are made in node-red by copying and pasting. Here come out tasks that no one has done before. If it fails,  will have to temporarily donate 4 esp. I will try to rework your project as soon as I understand at least a little what to do)

Closed 2024-11-15.

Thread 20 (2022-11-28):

folder.ino

tiruds76, 2022-11-28:
Hello I start with Arduino and I don't understand how to add the code? I can't find a.ino file in your folder

eg321, 2022-11-29:
Hi!
This project was developed in Platformio: https://platformio.org/
You can try to install it and open this project. All dependencies will be installed automatically.

I can't keep this issue open, because it's not related to the project. I believe you'll find assistance at Platformio related resources.
Will be glad to see you again with Platformio and successful compilation of this project.
Good luck!

Closed 2022-11-29.

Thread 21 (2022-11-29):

calibration not work

tiruds76, 2022-11-29:

tiruds76, 2022-11-30:
I compiled again project with version 2.1but I am blocked at the compilation because of 4 errors he says in the Steppehelper file:
	"message": "'class CheapStepper' has no member named 'getPin'",

eg321, 2022-11-30:
hm?

Closed 2022-11-30.

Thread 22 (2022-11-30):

connexion wifi

tiruds76, 2022-11-30:
Hello I installed version 2.0.1 but I still have wifi connection problems when I disconnect it for a while when I connect it again it connects and disconnects as early

eg321, 2022-11-30:
Hi,
what hardware do you use? esp32/8266?

Please connect esp by serial and provide logs from console for that period when you see connection issues.

tiruds76, 2022-11-30:
esp8266 I just saw by plugging that I had an 890s count ...

tiruds76, 2022-12-01:
Is the code configure with a deepsleep for use with a 9 volts battery?

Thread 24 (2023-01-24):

Apple HomeKit future support?

kpbicka, 2023-01-24:
Добрый день, разработчик!
Возможно ли добавить интеграцию с Apple HomeKit ?
Ваш проект гораздо мощнее других существующих и поддержка имеется, поэтому и спрашиваю)
Спасибо!

eg321, 2023-02-03:
приветствую,

лично я экосистему от Apple не использую вообще, поэтому даже физически не смогу это реализовать. Если кто-то окажет помощь в реализации - буду рад принять пулл реквест или обсудить детали реализации.

На данный момент возможна интеграция с Apple Homekit / Google Home через сторонние сервисы умного дома типа HomeAssistant или OpenHab.

В любом случае, оставлю этот реквест открытым.
Спасибо!

-----
Hi,

I do not use Apple ecosystem at all personally, therefore cannot implement such support. I'll be glad to discuss implementation or review pull request, if anyone want contribute.

In general you can integrate your blinds with Apple homekit / GoogleHome through services like HomeAssistant / Openhab.

Anyway, I'll keep this issue opened as Feature Request.
Thanks!

kpbicka, 2023-02-06:
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

Спасибо за ответ. Не знаю, поможет ли, но все проекты делают на основе maximkulkin /esp-homekit
Сам я не программер, поэтому и просил)

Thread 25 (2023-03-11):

Failed to open config file

nab240100, 2023-03-11:
after connecting to the ap and setting up the motor pins, saving and resetting it wont connect to my wifi.
i'm using a nodemcu v3 board and have little to no experience with platformio, but i think i know the basics.

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

eg321, 2023-03-12:
Hi,

why do you think it's not connected to your WiFi? According to  your screenshot it does (IP is assigned - 192.168.100.92).

nab240100, 2023-03-15:
hi, thank you very much for replying.  i checked the devices connected on lan from cmd and i cant see the listed ip with arp -a.

the messages on the screenshot from the serial monitor keeps looping from start to finish.
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

i tried flashing the release nodemcuv2.bin with the given instructions and got the same result as with platformio.
before flashing with platform io i erase the board too.

eg321, 2023-03-18:
It looks like your board rebooted by watchdog. There is issue with stepper pins initialization according to your log.

Have you checked that these pins are available for use at nodemcu v2? I've quickly googled for pinouts and can't find pins 19 and 20 at all.

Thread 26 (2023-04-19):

Control via MQTT

DennisRoschke, 2023-04-19:
Hey, unfortunately I don't understand which commands can be sent via MQTT to enable an action.
for example to lower the blinds.

eg321, 2023-04-21:
Hi,
unfortunately it's not documented well, but actually it's simple. Just 2 things to know:
1. What topics are used described here: https://github.com/eg321/esp32-motorized-roller-blinds#mqtt
2. How to pack your data you can see at WebUI in Websocket channel (MQTT uses same messages):
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
So, to move your blinds lower you can send something like this:
```json
{num: 1, action: "auto", value: 100}
```
this means: stepper №1 should automatically move blinds into 100% position (fully closed).
It's a main scenario, but another commands (f. e. to calibrate your blinds or stop movement) you can find here: https://github.com/eg321/esp32-motorized-roller-blinds/blob/master/src/main.cpp#L135

DennisRoschke, 2023-04-24:
Thanks it Works

Closed 2023-04-24.

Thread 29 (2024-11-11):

Motor issues.

ZlobidloCZ, 2024-11-11:
Hi, I uploaded to the D1 mini USB C version and am having issues with the motor not spinning and not turning off the coils, which is draining power. Has anyone encountered this issue?

eg321, 2024-11-12:
Hi!
You've configured GPIO incorrectly most probably.
Can you describe/show your setup?

ZlobidloCZ, 2024-11-12:
I could not find any configuration in the code, and I tried every combination of D1-4 with INTs. In the web config, I set 1,2,3,4 as I use D1-4 for the board. It works without any issue on the previous software on which yours is built. So is there a way to configure D1 mini in firmware?

eg321, 2024-11-13:
Pins should be configured at Captive portal: https://github.com/eg321/esp32-motorized-roller-blinds?tab=readme-ov-file#captive-portal

Did you tried this?

ZlobidloCZ, 2024-11-13:
Yes I did this configuration, I placed 1,2,3,4 in motor 1 because I have only one motor hooked up. And I got just Humm from the motor and also the coils did not turn off the whole time.

eg321, 2024-11-13:
Did you checked that these pins are really 1,2,3,4 ? Please share photo where we can see pins and connections.

ZlobidloCZ, 2024-11-13:
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
Here is the picture, D1 is INT1, and so on.

eg321, 2024-11-14:
According to pic below, correct pin numbers are 5, 4, 0 and 2:
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

You need to reset and correct pin numbers.

eg321, 2024-11-15:
You're welcome.
Yes, buttons will control all motors at once. It will be triggered by high-level (3.3v for esp8266) as I remember.

Closed 2024-11-15.

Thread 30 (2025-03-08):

Reversing rotation direction

MarkoJanne, 2025-03-08:
Would it be possible to reverse rotation direction without modifying and reinstalling everything. I tried to swap wires to ULN2003 driver without success.

eg321, 2025-03-10:
Hi, AFAIK you can just swap any 2 wires to reverse direction. I'm sure that mis-wiring will cause reversed direction. Just check it.

Closed 2025-03-10.

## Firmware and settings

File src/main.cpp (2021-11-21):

#define LONG_PRESS_MS 1000      // How much ms you should hold button to switch to "long press" mode (tune blinds position)
#define MAX_STEPPERS_COUNT 4    // This limited by available pins usually
/*
Usually your home automation can extract needed data from single JSON with info about all steppers.
These separate updates for specific steppers will additionally stuck all steppers for some milliseconds.
Do you really want this?
*/
#define MQTT_UPDATES_PER_STEPPER false

#define NUMBER_OF_CLICKS_TO_RESTART 5 //How many clicks of Up/Down button needed to restart controller

#define WIFI_FAILURE_TIMEOUT 15 * 60 // How many seconds to wait for connection restoration before restart (affects captive portal too)

#define HA_AUTODISCOVERY_PREFIX "homeassistant"

#include <CheapStepper.h>
//#include <ESP8266mDNS.h>
//#include <WiFiUdp.h>

#include <WebSocketsServer.h>
#include <ArduinoOTA.h>
#include <ArduinoJson.h>
#include <WiFiSettings.h>
#include "Helpers/ConfigHelper.h"
#include "Helpers/MqttHelper.h"
#include "Helpers/ButtonsHelper.h"
#include "Helpers/StepperHelper.h"
#include "index_html.h"
#include <string>

//----------------------------------------------------

// Version number for checking if there are new code releases and notifying the user
String version = "2.0.1";

ConfigHelper helper = ConfigHelper();
MqttHelper mqttHelper = MqttHelper();
ButtonsHelper buttonsHelper = ButtonsHelper();
StepperHelper stepperHelpers[MAX_STEPPERS_COUNT];

String deviceHostname;             //WIFI config: Bonjour name of device
int steppersRPM;                   //WIFI config
int state = 0;
long lastPublish = 0;

boolean loadDataSuccess = false;
boolean saveItNow = false;          //If true will store positions to filesystem
boolean initLoop = true;            //To enable actions first time the loop is run

#ifdef ESP32
WebServer server(80);              // TCP server at port 80 will respond to HTTP requests
#else
ESP8266WebServer server(80);              // TCP server at port 80 will respond to HTTP requests
#endif

WebSocketsServer webSocket = WebSocketsServer(81);  // WebSockets will respond on port 81

bool loadConfig() {
    if (!helper.loadconfig()) {
        return false;
    }
    JsonObject &root = helper.getconfig();

    root.printTo(Serial);
    Serial.println();

    //Store variables locally
    uint8_t num = 0;
    for (StepperHelper &stepperHelper : stepperHelpers) {
        num++;
        if (stepperHelper.isConnected()) {
            stepperHelper.currentPosition = root["currentPosition" + String(num)]; // 400
            stepperHelper.maxPosition = root["maxPosition"+ String(num)]; // 20000
        }
    }

    return true;
}

/**
   Save configuration data to a JSON file
*/
bool saveConfig() {
    const size_t capacity = JSON_OBJECT_SIZE(MAX_STEPPERS_COUNT * 2);
    DynamicJsonBuffer jsonBuffer(capacity);
    JsonObject &json = jsonBuffer.createObject();
    uint8_t num = 0;
    for (StepperHelper stepperHelper : stepperHelpers) {
        num++;
        if (stepperHelper.isConnected()) {
            json["currentPosition" + String(num)] = stepperHelper.currentPosition;
            json["maxPosition" + String(num)] = stepperHelper.maxPosition;
        }
    }

    return helper.saveconfig(json);
}

void sendUpdate() {
    uint8_t num = 0;
    DynamicJsonBuffer jsonBuffer(200);
    JsonObject& root = jsonBuffer.createObject();
    for (StepperHelper &stepperHelper : stepperHelpers) {
        num++;
        if (stepperHelper.isConnected()) {
            if (stepperHelper.maxPosition != 0) {
                stepperHelper.set = (stepperHelper.targetPosition * 100) / stepperHelper.maxPosition;
                stepperHelper.pos = (stepperHelper.currentPosition * 100) / stepperHelper.maxPosition;
            }
            root["set" + String(num)] = stepperHelper.set;
            root["position" + String(num)] = stepperHelper.pos;

#if MQTT_UPDATES_PER_STEPPER
            if (mqttHelper.isMqttEnabled && mqttHelper.getClient().connected()) {
                mqttHelper.publishMsg(mqttHelper.getTopicPath("out" + String(num)),
                                    String(stepperHelper.pos));
            }
#endif
        }
    }

    char jsonOutput[128]; //@TODO: Calculate capacity for JSON
    root.printTo(jsonOutput);
    Serial.println("Broadcasting JSON:" + String(jsonOutput));

    if (mqttHelper.isMqttEnabled && mqttHelper.getClient().connected()) {
        mqttHelper.publishMsg(mqttHelper.outputTopic, jsonOutput);
    }

    webSocket.broadcastTXT(jsonOutput);
}

/****************************************************************************************
*/
void processCommand(const String& command, const String& value, int stepperNum, uint8_t clientId) {
    if (command == "update") { //Send position details to the newly connected client
        sendUpdate();
        return;
    } else if (command == "ping") {
        //Do nothing
        return;
    };

    if (!stepperHelpers[stepperNum - 1].isConnected()) {
        Serial.printf("Stepper %i is not connected. Ignoring command '%s' from client %i...\r\n",
                      stepperNum,
                      command.c_str(),
                      clientId);
        Serial.println();
        return;
    }

    StepperHelper* stepperHelper = &stepperHelpers[stepperNum - 1];

    /*
       Below are actions based on inbound MQTT payload
    */
    if (command == "start") { // Store the current position as the start position
        stepperHelper->currentPosition = 0;
        stepperHelper->route = 0;
        stepperHelper->action = "manual";
        saveItNow = true;
    } else if (command == "max") { // Store the max position of a closed blind
        stepperHelper->maxPosition = stepperHelper->currentPosition;
        stepperHelper->route = 0;
        stepperHelper->action = "manual";
        saveItNow = true;
    } else if (command == "stop") { // STOP!
        stepperHelper->route = 0;
        stepperHelper->action = "";
        saveItNow = true;
    } else if (command == "manual" && value == "1") { // Move down without limit to max position
        stepperHelper->route = 1;
        stepperHelper->action = "manual";
    } else if (command == "manual" && value == "-1") { // Move up without limit to top position
        stepperHelper->route = -1;
        stepperHelper->action = "manual";
    } else {
        /*
           Any other message will take the blind to a position
           Incoming value = 0-100
        */
        Serial.println("New position command: " + value + "%");

        stepperHelper->targetPosition = stepperHelper->maxPosition * value.toInt() / 100;
        stepperHelper->route = stepperHelper->currentPosition < stepperHelper->targetPosition ? 1 : -1;
        stepperHelper->action = "auto";

        stepperHelper->set = value.toInt();
        stepperHelper->pos = (stepperHelper->currentPosition * 100) / stepperHelper->maxPosition;

        Serial.printf("Starting movement of Stepper %i (current position = %i, targetPosition = %i)...\r\n",
                      stepperNum,
                      stepperHelper->currentPosition,
                      stepperHelper->targetPosition);
        stepperHelper->getStepper()->newMove(stepperHelper->route == 1,
                                            abs(stepperHelper->currentPosition - stepperHelper->targetPosition));

        //Send the instruction to all connected devices
        sendUpdate();
    }
}

void processRequest(String &payload, uint8_t client_id = 0) {
    StaticJsonBuffer<100> jsonBuffer; //@TODO: Check capacity for JSON object
    JsonObject &root = jsonBuffer.parseObject(payload);
    if (root.success()) {
        const int stepperNum = root["num"];
        String command = root["action"];
        String value = root["value"];
        //Send to common MQTT and websocket function
        processCommand(command, value, stepperNum, client_id);
    } else {
        Serial.println("parseObject() failed");
    }
}

void webSocketEvent(uint8_t clientId, WStype_t type, uint8_t *payload, size_t length) {
    switch (type) {
        case WStype_CONNECTED:
            Serial.printf("[client %u] connected...\r\n", clientId);
            break;
        case WStype_DISCONNECTED:
            Serial.printf("[client %u] disconnected.\r\n", clientId);
            break;
        case WStype_TEXT:
            Serial.printf("[client %u] payload: %s\r\n", clientId, payload);
            String request = (char *) payload;
            processRequest(request, clientId);
            break;
    }
}

void mqttCallback(char *topic, byte *payload, unsigned int length) {
    Serial.print("MQTT message received [");
    Serial.print(topic);
    Serial.print("] ");
    String jsonRequest = "";
    for (auto i = 0; i < length; i++) {
        jsonRequest += String((char) payload[i]);
    }
    processRequest(jsonRequest);
}

void handleRoot() {
    server.send(200, "text/html", INDEX_HTML);
}

void handleNotFound() {
    String message = "File Not Found\n\n";
    message += "URI: ";
    message += server.uri();
    message += "\nMethod: ";
    message += (server.method() == HTTP_GET) ? "GET" : "POST";
    message += "\nArguments: ";
    message += server.args();
    message += "\n";
    for (uint8_t i = 0; i < server.args(); i++) {
        message += " " + server.argName(i) + ": " + server.arg(i) + "\n";
    }
    server.send(404, "text/plain", message);
}

void setupOTA() {
    // Authentication to avoid unauthorized updates
    //ArduinoOTA.setPassword(OTA_PWD); //@TODO: make it configurable

    ArduinoOTA.setHostname(deviceHostname.c_str());

    ArduinoOTA.onStart([]() {
        Serial.println("Start OTA");
    });
    ArduinoOTA.onEnd([]() {
        Serial.println("\nEnd OTA");
    });
    ArduinoOTA.onProgress([](unsigned int progress, unsigned int total) {
        Serial.printf("OTA Progress: %u%%\r\n", (progress / (total / 100)));
    });
    ArduinoOTA.onError([](ota_error_t error) {
        Serial.printf("OTA Error[%u]: ", error);
        if (error == OTA_AUTH_ERROR) Serial.println("Auth Failed");
        else if (error == OTA_BEGIN_ERROR) Serial.println("Begin Failed");
        else if (error == OTA_CONNECT_ERROR) Serial.println("Connect Failed");
        else if (error == OTA_RECEIVE_ERROR) Serial.println("Receive Failed");
        else if (error == OTA_END_ERROR) Serial.println("End Failed");
    });

    ArduinoOTA.begin();
}

void restartDevice() {
    Serial.println("Restarting...");
    delay(500);

#ifdef ESP8266
    ESP.reset();
#else   //ESP32
    ESP.restart();
#endif
}

void onPressHandler(Button2 &btn) {
    Serial.println("onPressHandler");
    String newValue;
    boolean isRestartRequested = false;

    if (btn == buttonsHelper.buttonUp) {
        Serial.println("Up button clicked");
        newValue = "0";
    } else if (btn == buttonsHelper.buttonDown) {
        Serial.println("Down button clicked");
        newValue = "100";
    }

    if (btn.getNumberOfClicks() == NUMBER_OF_CLICKS_TO_RESTART) {
        Serial.print(btn.getNumberOfClicks());
        Serial.println(" times clicked.");
        isRestartRequested = true;
    }

    uint8_t num = 0;
    for (StepperHelper &stepperHelper : stepperHelpers) {
        num++;
        if (stepperHelper.isConnected()) {
            if (isRestartRequested || (stepperHelper.route == -1 && newValue == "0") || (stepperHelper.route == 1 && newValue == "100")) {
                // Another click to the same direction will cause stopping
                processCommand("stop", "", num, BUTTONS_CLIENT_ID);
            } else {
                processCommand("auto", newValue, num, BUTTONS_CLIENT_ID);
            }
        }
    }

    if (isRestartRequested) {
        restartDevice();
    }
}

void onReleaseHandler(Button2 &btn) {
    Serial.print("onReleaseHandler. Button released after (ms): ");
    Serial.println(btn.wasPressedFor());
    if (btn.wasPressedFor() > LONG_PRESS_MS) {
        uint8_t num = 0;
        for (StepperHelper &stepperHelper : stepperHelpers) {
            num++;
            if (stepperHelper.isConnected()) {
                processCommand("stop", "", num, BUTTONS_CLIENT_ID);
            }
        }
    }
}

void checkWiFiConnection() {
    static unsigned long lastCheckTime = 0;
    static unsigned int failureTime = 0;
    unsigned long now = millis();

    if (WiFi.status() != WL_CONNECTED && now > lastCheckTime + (30 * 1000)) {
        if (failureTime == 0) {
            Serial.println("WiFi connection failure. Starting timer to restart device...");
            failureTime = now;
        }

        Serial.printf("%i seconds until restart.\n", abs((int)(now - failureTime - WIFI_FAILURE_TIMEOUT * 1000) / 1000));
        if (now > failureTime + WIFI_FAILURE_TIMEOUT * 1000) {
            Serial.println("Restarting device...");
            restartDevice();
        }

        lastCheckTime = now;
    } else if (failureTime != 0 && WiFi.status() == WL_CONNECTED) {
        Serial.println("WiFi connection is restored.");
        failureTime = 0;
    }
}

void sendHADiscovery() {
    static boolean isHADiscoveryWasSent = false;
    if (isHADiscoveryWasSent || !mqttHelper.isMqttEnabled || !mqttHelper.getClient().connected()) return;

    Serial.println("Sending HA Autodiscovery packets...");

    isHADiscoveryWasSent = true;
    String haConfig;
    uint32_t chipId = ESP_getChipId();

    uint8_t num = 0;
    for (StepperHelper stepperHelper : stepperHelpers) {
        num++;
        if (stepperHelper.isConnected()) {
            haConfig = "{\"~\":\"" + mqttHelper.prefix + "/" + String(chipId) + "\","
                "\"name\":\"Rollerblind " + String(num) + "\",\n"
                "\"uniq_id\":\"" + String(chipId) + "_" + String(num) + "\","
                "\"dev_cla\":\"blind\","
                "\"avty_t\":\"~/available\","
                "\"cmd_t\":\"~/in\","
                "\"set_pos_t\":\"~/in\","
                "\"set_pos_tpl\":\"{\\\"num\\\": " + String(num) + ", \\\"action\\\": \\\"auto\\\", \\\"value\\\": {{ 100 - position }} }\",\n"
                "\"pos_t\":\"~/out\",\n"
                "\"pos_tpl\":\"{{ value_json.position" + String(num) + " }}\",\n"
                "\"pl_open\":\"{\\\"num\\\": " + String(num) + ", \\\"action\\\": \\\"auto\\\", \\\"value\\\": 0}\",\n"
                "\"pl_cls\":\"{\\\"num\\\": " + String(num) + ", \\\"action\\\": \\\"auto\\\", \\\"value\\\": 100}\",\n"
                "\"pl_stop\":\"{\\\"num\\\": " + String(num) + ", \\\"action\\\": \\\"stop\\\", \\\"value\\\": 0}\",\n"
                "\"pos_open\":0,\n"
                "\"pos_clsd\":100,\n"
                "\"opt\":false,"
                "\"dev\":{\"ids\":\"" + String(chipId) + "\",\"name\":\"ESP Motorized RollerBlinds\",\"mf\":\"https://github.com/eg321/esp32-motorized-roller-blinds\",\"sw\":\"" + version + "\",\"cu\":\"http://" + WiFi.localIP().toString() + "\",\"mdl\":\"DIY\"} "
            "}";
        } else {
            haConfig = ""; // empty payload will cause a previously discovered device to be deleted
        }

        mqttHelper.publishMsg(
            String(HA_AUTODISCOVERY_PREFIX) + "/cover/" + String(chipId) + "_" + String(num) + "/config",
            haConfig,
            true
        );
    }
}

void setup(void) {
    Serial.begin(115200);
    delay(100);

    Serial.println("Starting now...");

//Load config upon start
    Serial.println("Initializing filesystem...");
#ifdef ESP32
    if (!SPIFFS.begin(true)) {
      Serial.println("Failed to mount file system");
      return;
    }
#else //ESP8266
    if (!LittleFS.begin()) {
        Serial.println("Failed to mount file system");
        return;
    }
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
void loop(void) {
    //OTA client code
    ArduinoOTA.handle();

    //Websocket listner
    webSocket.loop();
#ifdef ESP32
    esp_task_wdt_reset();
#else //ESP8266
    ESP.wdtFeed();
#endif

    if (buttonsHelper.useButtons) {
        buttonsHelper.processButtons();
    }

    /**
      Serving the webpage
    */
    server.handleClient();

    mqttHelper.loop();

    checkWiFiConnection();

    /**
      Storing positioning data and turns off the power to the coils
    */
    if (saveItNow) {
        saveConfig();
        saveItNow = false;

        stopPowerToCoils();
    }

    /**
      Manage actions. Steering of the blind
    */
    uint8_t num = 0;
    bool isTimeToSendUpdate = false;
    for (StepperHelper &stepperHelper : stepperHelpers) {
        num++;
        if (!stepperHelper.isConnected()) {
            continue;
        }
        if (stepperHelper.action == "auto") {
            stepperHelper.getStepper()->run();
            stepperHelper.currentPosition = stepperHelper.targetPosition - stepperHelper.getStepper()->getStepsLeft();
            if (stepperHelper.currentPosition == stepperHelper.targetPosition) {
                stepperHelper.route = 0;
                stepperHelper.action = "";
                stepperHelper.set = (stepperHelper.targetPosition * 100) / stepperHelper.maxPosition;
                stepperHelper.pos = (stepperHelper.currentPosition * 100) / stepperHelper.maxPosition;
                sendUpdate();
                Serial.printf("Stepper %i has reached target position.\r\n", num);
                saveItNow = true;
                isTimeToSendUpdate = true;
            }
        } else if (stepperHelper.action == "manual" && stepperHelper.route != 0) {
            stepperHelper.getStepper()->move(stepperHelper.route > 0, abs(stepperHelper.route));
            stepperHelper.currentPosition += stepperHelper.route;
        }

        if (stepperHelper.action != "") {
            isTimeToSendUpdate = true;
        }
    }

    if (isTimeToSendUpdate) {
        long now = millis();
        if (now - lastPublish > 3000) { // Update state
            lastPublish = now;
            sendUpdate();
        }
    }

    /*
       After running setup() the motor might still have
       power on some of the coils. This is making sure that
       power is off the first time loop() has been executed
       to avoid heating the stepper motor draining
       unnecessary current
    */
    if (initLoop) {
        initLoop = false;
        stopPowerToCoils();
    }
}

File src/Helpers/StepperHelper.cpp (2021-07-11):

#include "StepperHelper.h"

CheapStepper* StepperHelper::getStepper() {
    if (stepper == nullptr) {
        int* pins;
        pins = parsePins();
        Serial.printf("Initializing Stepper using pins: %i %i %i %i ...\r\n", pins[0], pins[1], pins[2], pins[3]);
        stepper = new CheapStepper(pins[0], pins[1], pins[2], pins[3]);
    }

    return stepper;
}

bool StepperHelper::isConnected() {
    return pinsStr.length() > 0;
}

int* StepperHelper::parsePins() {
    static int pins[4];
    sscanf(pinsStr.c_str(), "%d,%d,%d,%d", &pins[0], &pins[1], &pins[2], &pins[3]);
    Serial.printf("Parsed pins for Stepper: %i %i %i %i\r\n", pins[0], pins[1], pins[2], pins[3]);

    return pins;
};

void StepperHelper::disablePowerToCoils() {
    auto stepper = getStepper();

    digitalWrite(stepper->getPin(0), LOW);
    digitalWrite(stepper->getPin(1), LOW);
    digitalWrite(stepper->getPin(2), LOW);
    digitalWrite(stepper->getPin(3), LOW);
}

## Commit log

2019-09-17 Project customization to 3 motors
    - project ported to Platformio
    - changed 3d parts according to small tube ~16mm
    - added functionality of 3 step motors
    - add current state broadcasting during blinds moving
    - add wipe setting function
    - add pcb sources
    [Sborka1.SLDASM, blinds_new.brd, blinds_new.sch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]
2020-01-09 Switched back to Stepper_28BYJ_48
2020-01-09 Updated 3d parts (Leroy Merlin version)
    [Leroy Merlin blind holder (direct drive).SLDPRT, Leroy Merlin blind holder (direct drive).STL, Motor holder (direct drive).SLDPRT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]
2020-09-13 ESP32 support, moving to CheapStepper, error handling for MQTT connection
    [main.cpp]
2021-04-28 Add support for Up / Down mechanical buttons
2021-07-05 Configure up/down buttons dynamically at portal
2021-07-08 TECH Automatically reformat code (4 spaces per tab + brackets)
2021-07-11 [v2.0] Dynamic configuration of steppers and pins at captive portal (huge refactoring)
2021-07-12 [v2.0] Buttons - another press to the same direction will cause stop of steppers
2021-07-12 [v2.0] "stop" is explicit command now + fixes with buttons
    [main.cpp]
2021-08-01 Insert images
2021-08-14 #1 Adding possibility to restart controller from mechanical buttons (5 clicks by default)
2021-11-07 #1 Check for WiFi connection and restart on failure timeout
    [MqttHelper.cpp, main.cpp]
2021-11-08 Make checking of intervals reliable (overflow issue)
    [MqttHelper.cpp]
2021-12-11 Resolve compilation issues for ESP8266 (abs -> fabs)
    [MqttHelper.cpp]
2024-09-22 Add ozon home blinds direct drive shaft
    [Ozon home blind shaft (direct drive).stl]
